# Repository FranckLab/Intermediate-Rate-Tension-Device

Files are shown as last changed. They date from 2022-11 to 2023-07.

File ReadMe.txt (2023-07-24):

===============================================================================
|          Complete design files for Intermediate-Rate Tension Device         |
-------------------------------------------------------------------------------
| L. Summey (1), J. Zhang (1), A. K. Landauer (2), J. Sergay (3), J. Yang (4),| 
| A. Daul (1), J. Tao (1), J. Park (1), A. McGhee (1), C. Franck (1)          |
|                                                                             |
| 1 Department of Mechanical Engineering, UW-Madison, Madison, WI, 53706      |
| 2 National Institute of Standards and Technology, Gaithersburg, MD, 20899   |
| 3 Department of Biomedical Engineering, UW-Madison, Madison, WI, 53706      |
| 4 Department of Aerospace Engineering & Engineering Mechanics, UT-Austin,   |
|   Austin, TX, 78712                                                         |
| July 19, 2023                                                               |
| see github.com/FranckLab/Intermediate-Rate-Tension-Device for contact info  |
| and other updates                                                           |
-------------------------------------------------------------------------------

*******************************************************************************

===============================================================================
|          Summary and description of use:                                    |
-------------------------------------------------------------------------------

These folders contain all the files necessary to assemble the published tension
device and the compatible test specimens. Files include CAD designs ready to 3D
print (.step), aluminum parts to cut (.step), photolithography sample mold
shapes (.dxf), and parts to purchase.

*******************************************************************************

===============================================================================
|              Tension device designs:                                        |
-------------------------------------------------------------------------------
- Tension Device Assembly.step (Assembly file for entire tension device with all individual parts that can be found in more
  detail below) 

- Device 3D Printed Parts (Parts to 3D print)
    + Motion Control Knob (Rotates the four T8 Lead Screws with the Timing Belt)
    + TensionDevice - Impact Grip (Connected to part '8381K3' which sits on the rail. A cylindrical magnet is placed in the
                                   top of the impact grip which connects the impact grip with a metal screw at the end of 
                                   the linear actuator of the motor)
    + *TensionDevice - Sample Dish Holder (Holder for a 1-well rectangular sample dish)
    + TensionDevice_Rail Mount (Connects the rail to the 'Z-Stage_Aluminum')
    + Timing Belt Tensioner (Placed on top of the 'TopPlate_Aluminum. A cylindrical piece must be placed in the top of it to
                             hold the timing belt in tension)

 - Device Purchased Parts (CAD of each part that needs to be purchased through 
   third party venders)
    + 8381K3 - Rail.step (Order 1 - Metal rail attached to 'TensionDevice_Rail Mount')
    + Aluminum Timing Pulley (20-60T-8B-6).step (Order 4 - Four placed on the top of the device, supports the timing belt)
    + BESTORQ 620-5M-9 5M Timing Belt.step (Order 1 - Wrapped around the 'Timing Pulley')
    + Mcmaster - 8381K3 (x2).step (Order 2 - Two placed on the 'Rail'. Connect each to one 'Impact Grip')
    + T8 Lead Screw (MOTOU 0791300576783).step (Order 4 - The four "pillars" seen in the Device Assembly)
    + T8 Pillow Block Bearing (MOTOU 0791300576783).step (Order 8 - Holds the 'lead screws'. Attach four into the
                                                          'NikonBasePlate'. Attach four into the 'TopPlate_Aluminum')
    + T8 anti-backlash Nut (MOTOU 0791300576783).step (Order 4 - Placed around each 'lead screw' and fits inside the four
                                                       holes of the 'Z-Stage_Aluminum')
    + Timing Belt.step (Order 1 - Placed around the 'timing pulleys')

 - Waterjet Cut Aluminum Parts (Aluminum parts to be created to the specifications of the CAD files with a watercut jet)
    + Tension Device_Z-Stage_Aluminum.step (Connected to the four T8 Lead Screws, the two impact grips, and the rail mount)
    + *TensionDevice_Nikon Baseplate Mount.step (Mounts motors to either side of the baseplate)
    + *TensionDevice_NikonBaseplate.step (Aluminum plate with dimensions that fit a microscope stage)
    + TensionDevice_TopPlate_Aluminum.step (Top of device to mount the rail and control knob)

* Denotes parts that might need to be adapted depending on the user's microscope system or sample dish size

===============================================================================
|              Test sample parts for various tensile speciments:              |
-------------------------------------------------------------------------------
The following files are used to create the parts needed for the samples tested in the tension device (as seen in Fig. 3
of the paper) 

- Samples
    + PDMS (Fig. 3A - thin dogbone-shaped specimen made from polydimethylsiloxane)
        + 10mm PDMS Sample - F_Gripper.step (one grip to hold specimen)
        + 10mm PDMS Sample - M_Gripper.step (one grip to hold specimen)
        + 10mm PDMS Sample - Holder (part to aid in the assembly of PDMS dogbones into the 2 grippers)
        + SU8 Patterned Figure - SU8.dxf (pattern used to create a dogbone mold from UV patterned SU8 on silicon wafers)
    + Foam (Fig. 3B - dogbone-shaped foam specimen)
	+ 2mmFoamSample - F_Gripper.step (one grip to hold specimen)
        + 2mmFoamSample - M_Gripper.step (one grip to hold specimen)
    + Hydrogel (Fig. 3C - hydrogel dogbone for 3D samples)
        + 7mm Hydrogel Mold - F-grip.step (one grip to hold the specimen)
        + 7mm Hydrogel Mold - M-grip.step (one grip to hold the specimen)
        + 7mm Hydrogel - Sample Mold.step (mold to pour the hydrogel into)

*******************************************************************************

===============================================================================
|              Compression Device:                                            |
-------------------------------------------------------------------------------
An additional folder has been added with parts needed to modify the tension device to be a compression device

- Compression Modifications
    + Compression - Baseplate for 155mm x 185mm Stage.step
    + Compression - Impact Grip.step
    + Compression - Magnetic Mount Plate.step
    + Compression - Rail Mount (One Motor).step
    + Compression - Sample Holder Base.step
    + Compression - Sample Holder Cap.step
    + Compression - Sample Mold Base.step
    + Compression - Sample Mold Side.step
    + Compression - Stationary Sample Grip.step
    + Compression Motor Mount Plate.step
    + Compression Sample - Stamp_Hamburger.step

*******************************************************************************

===============================================================================
|              Citation                                                       |
-------------------------------------------------------------------------------
TBD

*******************************************************************************

===============================================================================
|              Contact and Support                                            |
-------------------------------------------------------------------------------
Email: Jing Zhang (jzhang2338@wisc.edu) or Prof. Christian Franck (cfranck@wisc.edu)

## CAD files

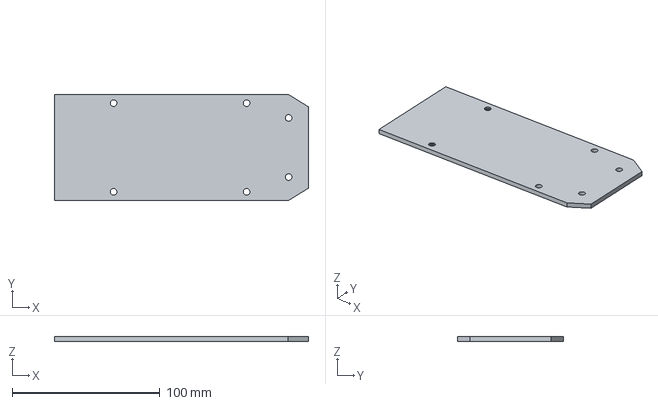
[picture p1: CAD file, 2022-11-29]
Compression Modifications/Compression Motor Mount Plate.step
171.9 x 72.0 x 3.17 mm

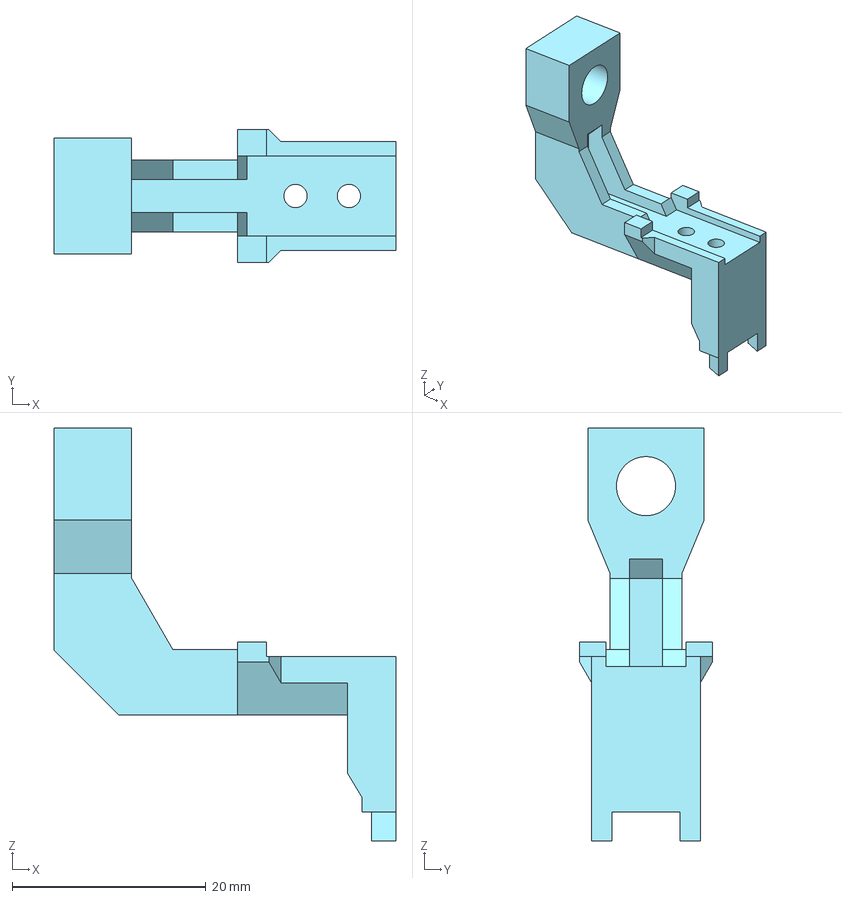
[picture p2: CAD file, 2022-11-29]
Device 3D Printed Parts/TensionDevice - Impact Grip (3D Print).step
35.3 x 13.7 x 42.6 mm

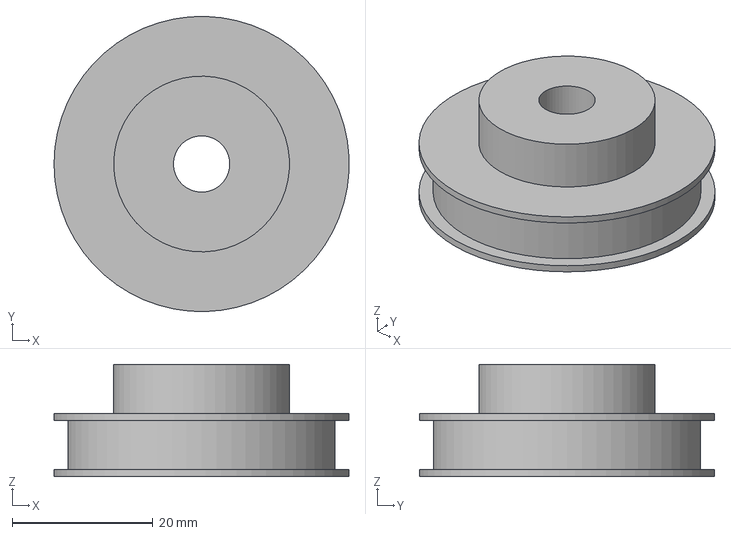
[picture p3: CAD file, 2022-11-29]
Device Purchased Parts/Aluminum Timing Pulley (20-60T-8B-6).step
42.0 x 42.0 x 16.0 mm

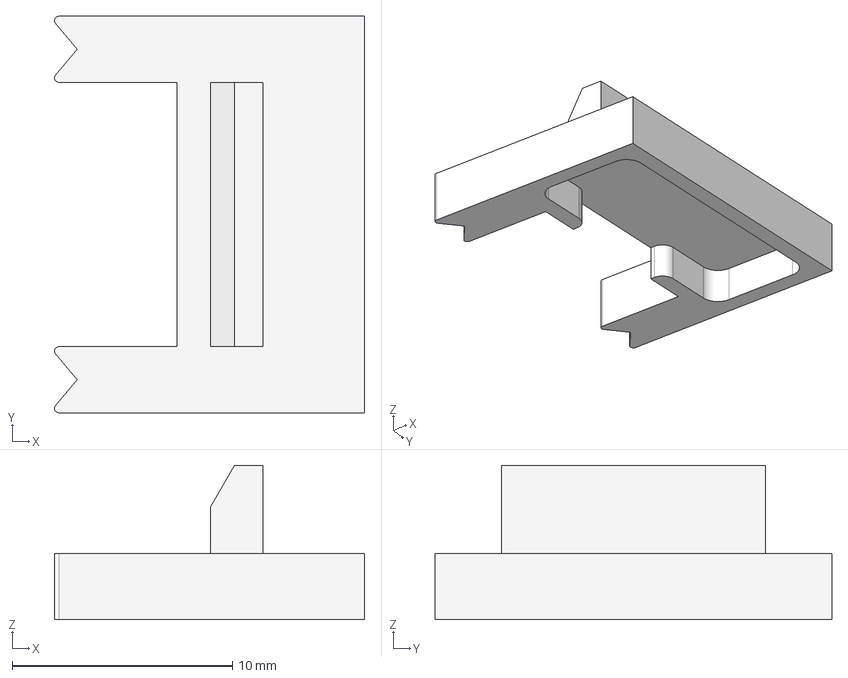
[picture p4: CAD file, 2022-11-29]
Samples/2mmFoamSample - F_Gripper.step
14.1 x 18.0 x 7.00 mm

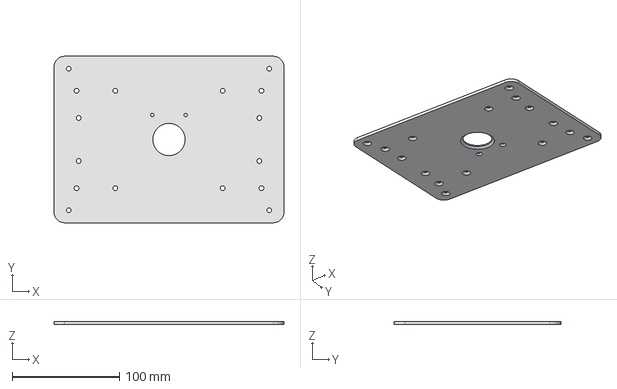
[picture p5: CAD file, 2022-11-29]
Waterjet Cut Aluminum Parts/TensionDevice_NikonBaseplate.step
214.0 x 155.0 x 3.17 mm

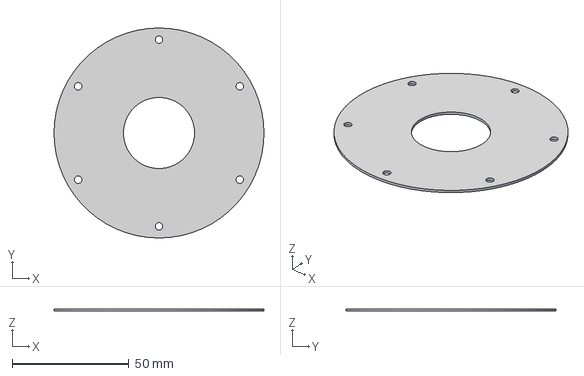
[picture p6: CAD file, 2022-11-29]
Compression Modifications/Compression - Magnetic Mount Plate.step
90.0 x 90.0 x 1.00 mm

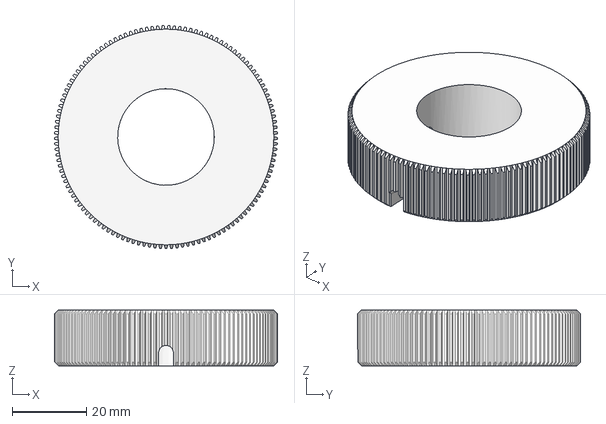
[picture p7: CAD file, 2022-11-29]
Device 3D Printed Parts/Motion Control Knob.step
60.0 x 60.0 x 15.0 mm

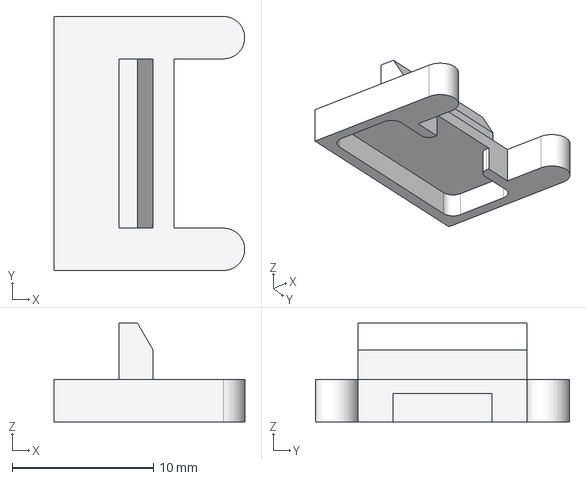
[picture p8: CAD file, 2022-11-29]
Samples/2mmFoamSample - M_Gripper.step
13.5 x 18.0 x 7.00 mm

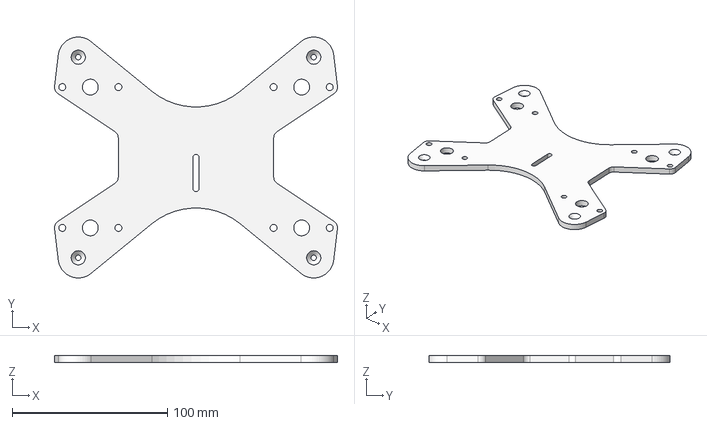
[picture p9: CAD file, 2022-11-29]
Waterjet Cut Aluminum Parts/TensionDevice_TopPlate_Aluminum.step
182.1 x 155.0 x 4.76 mm

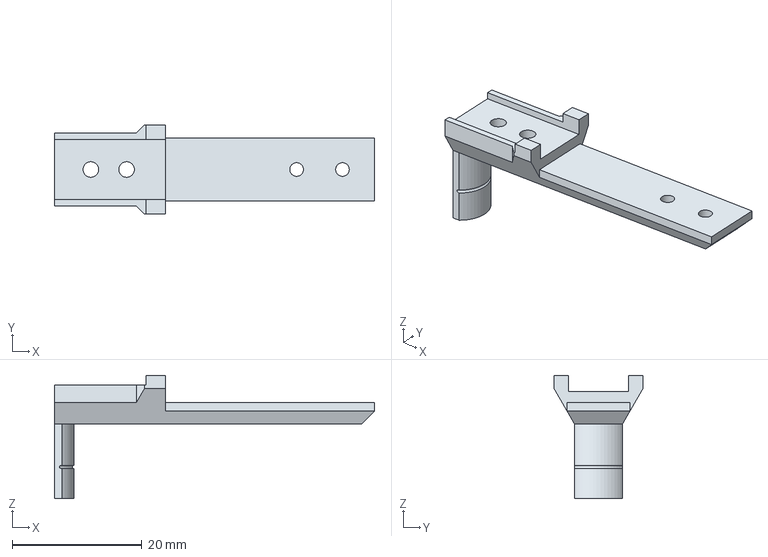
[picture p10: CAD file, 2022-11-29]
Compression Modifications/Compression - Stationary Sample Grip.step
49.3 x 13.7 x 19.0 mm

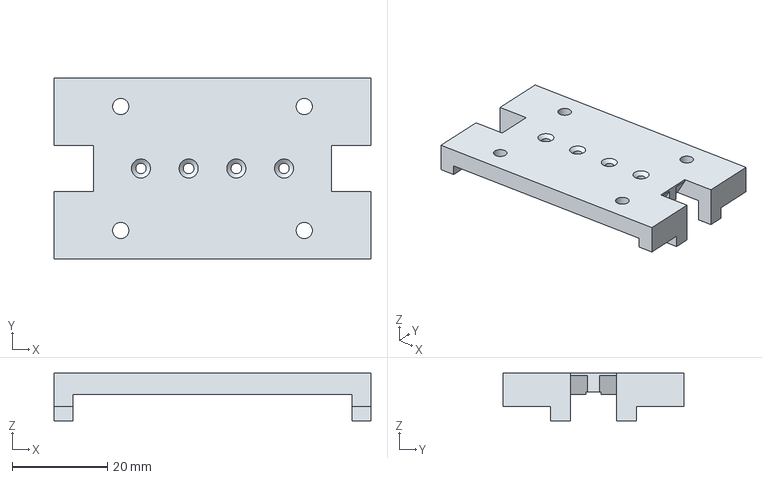
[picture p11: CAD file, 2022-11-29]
Device 3D Printed Parts/TensionDevice_Rail Mount - 3D Print.step
66.5 x 38.0 x 10.00 mm

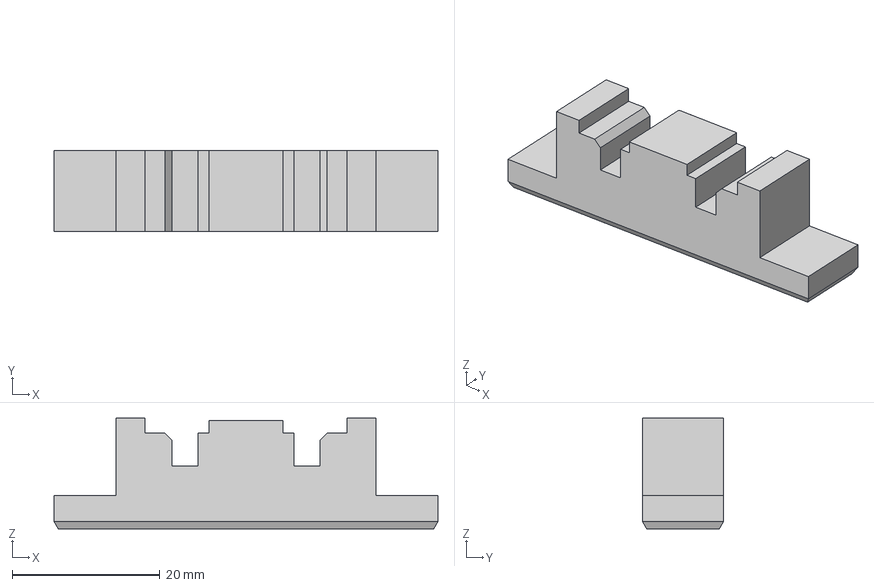
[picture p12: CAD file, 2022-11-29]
Samples/10mm PDMS Sample - Holder.step
52.0 x 11.0 x 15.0 mm

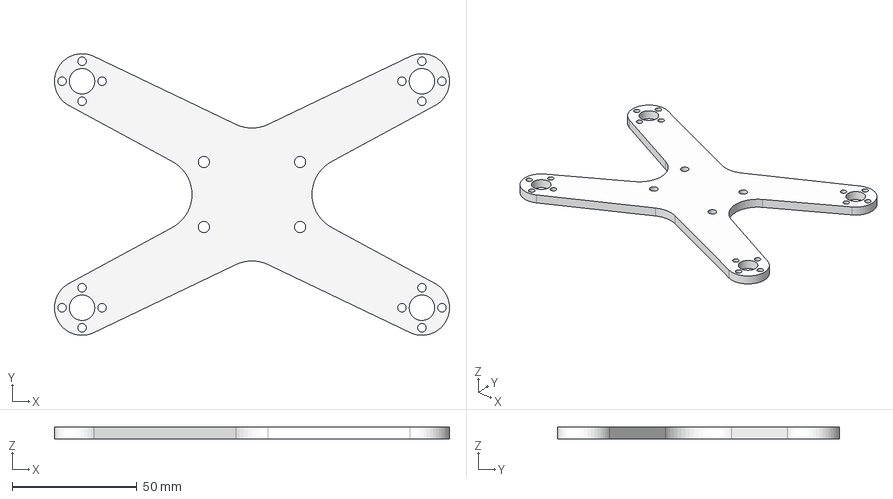
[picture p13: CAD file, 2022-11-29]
Waterjet Cut Aluminum Parts/Tension Device_Z-Stage_Aluminum.step
158.0 x 112.6 x 4.76 mm

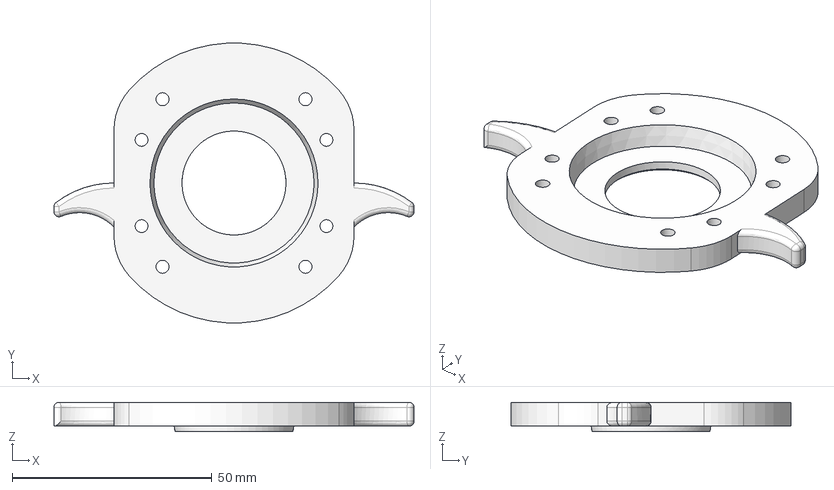
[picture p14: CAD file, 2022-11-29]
Compression Modifications/Compression - Sample Holder Base.step
90.0 x 69.9 x 7.38 mm

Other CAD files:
SU8 Patterned Figure - SU8.dxf
Device 3D Printed Parts/TensionDevice - Sample Dish Holder.step
Device Purchased Parts/8381K3 - Rail.step
Samples/7mm Hydrogel - Sample Mold.step
Compression Modifications/Compression - Baseplate for 155mm x 185mm Stage.step
Compression Modifications/Compression - Impact Grip.step
Compression Modifications/Compression - Rail Mount (One Motor).step
Compression Modifications/Compression - Sample Holder Cap.step
Compression Modifications/Compression - Sample Mold Base.step
Compression Modifications/Compression - Sample Mold Side.step
Compression Modifications/Compression Sample - Stamp_Hamburger.step
Device 3D Printed Parts/Timing Belt Tensioner.step
Device Purchased Parts/BESTORQ 620-5M-9 5M Timing Belt.step
Device Purchased Parts/Mcmaster - 8381K3 (x2).step
Device Purchased Parts/T8 Lead Screw (MOTOU 0791300576783).step
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

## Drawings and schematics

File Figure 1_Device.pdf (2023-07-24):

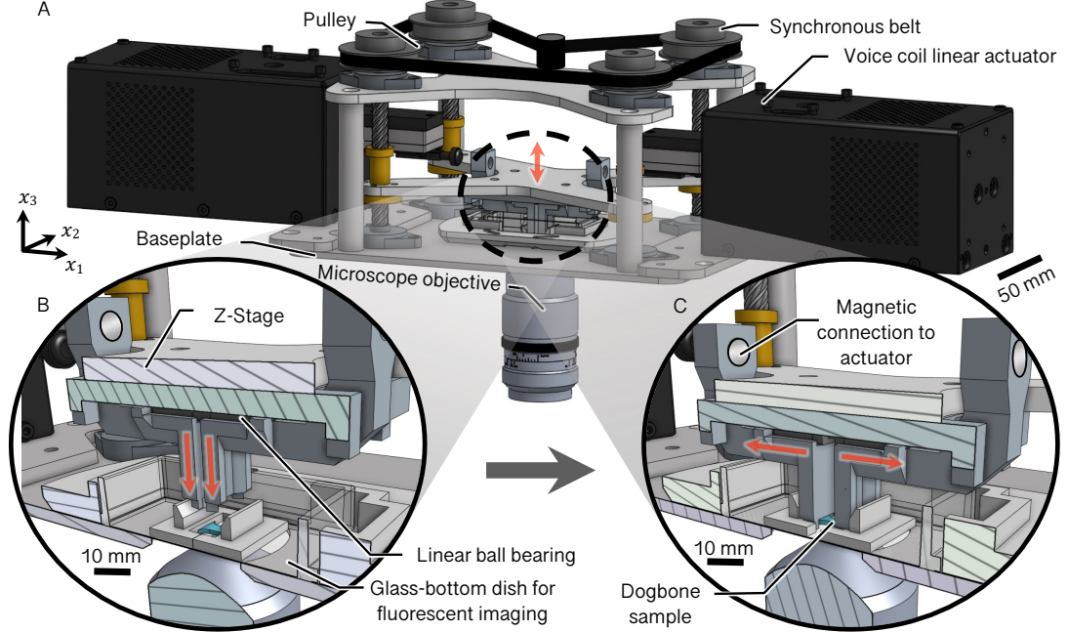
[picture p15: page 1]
Pulley; Synchronous belt; Z-Stage; Microscope objective; Dogbone sample; Baseplate; Magnetic connection to actuator

Voice coil linear actuator

Linear ball bearing
Glass-bottom dish for
fluorescent imaging
